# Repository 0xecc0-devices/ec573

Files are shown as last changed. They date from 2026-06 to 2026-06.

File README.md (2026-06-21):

# ec573 - Amiga 500 8MB Z2 DRAM + 2 channel IDE controller

## description
The ecc0 573 - or ec573 - is an Amiga 500 internal 8MB DRAM Zorro II expansion with 2 channel autoboot IDE controller sitting under the MC68000 CPU. It does fit into a standard Amiga 500 Mainboard interfering with neither ROM nor expansion connector.

### rendered pcb
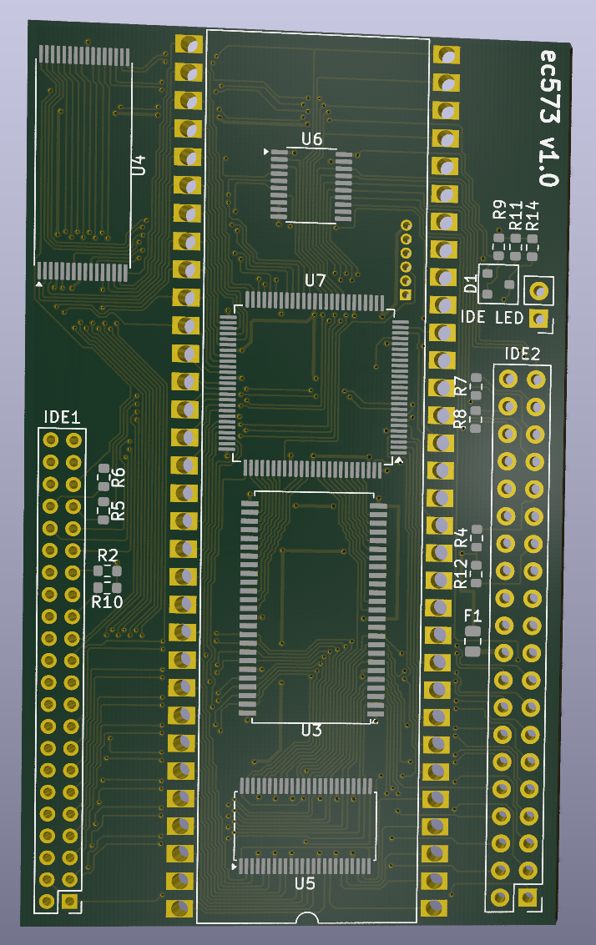
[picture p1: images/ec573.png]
rendered ec573 v1.0 pcb


### real pcb
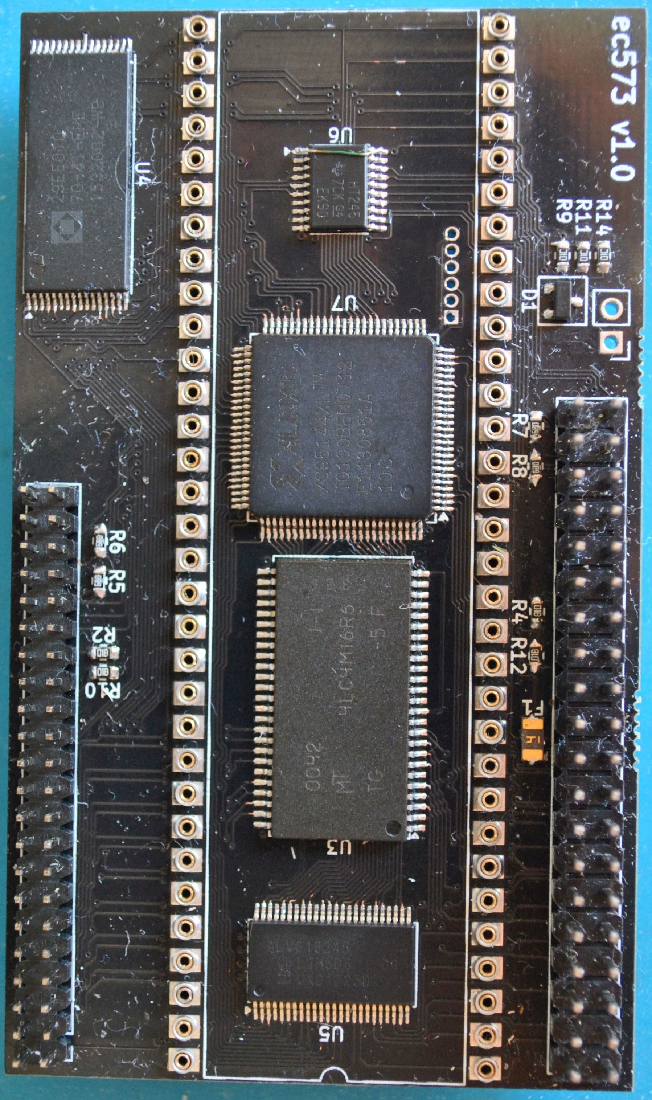
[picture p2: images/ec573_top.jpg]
real hardware ec573 v1.0

### fitted into A500
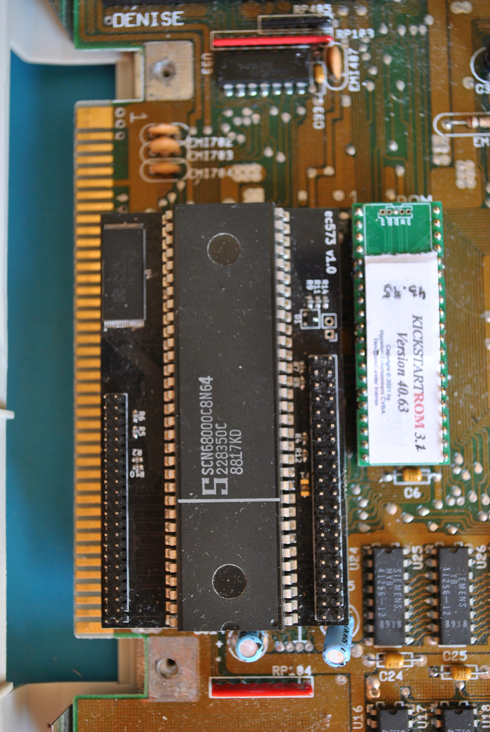
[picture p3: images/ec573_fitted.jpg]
ec573 v1.0 fitted into A500


DRAM and IDE controller are added using Amiga autoconfig mechanism with chain snooping. The expansion requires at least Kickstart 2.04 (v37.299).

## features

 - 8MB DRAM Zorro II memory expansion
  - IDE controller with 2 channels for 4 devices using the fabulous [lide.device](https://github.com/LIV2/lide.device)
 - full Zorro II autoconfig
 - jumperless
 - 2,5" IDE connector
 - 3,5" IDE connector with +5V power supply (fused on pin 20)
 - IDE LED connector
 - 128kB IDE controller ROM with CD boot capability
 - IDE autoboot ROM in circuit flash updateable
 - compatible with Kickstart v37.299 (2.04) and later

## technical details
 - 8MB DRAM mapped into Amiga's Zorro II memory address space ($20.0000 - $9F.FFFF)
 - 128kB IDE controller mapped as I/O device into Amiga's Zorro II I/O address space
 - 15,6 &#xb5;S DRAM CBR refresh

## limitations
The ecc0 573 has been designed to achieve several goals. This leaves the finished design with limitations which are intended, yet to be made transparent.

1. Due to the absense of Amiga Zorro Autoconfig signals **cfgin** and **cfgout** on the CPU slot, a snooping mechanism waits for all other devices to be configured first. This snooping mechanism needs at least Kickstart v37.299 to work.
2. Neither DRAM nor IDE controller are deactivateable.
3. The Zorro II DRAM size is fixed to 8MB. If another autoconfig device is claiming any memory before, none of the expansion's DRAM will be available.
4. The IDE controller uses [lide.device](https://github.com/LIV2/lide.device) by Matt Harlum as autoboot firmware thus inheriting all it's limitations.
5. The expansion always configures last in the autoconfiguration chain and uses the remaining resources available.
<!--stackedit_data:
eyJoaXN0b3J5IjpbMTAzMzAxODg2NSwtMTc1ODM2NjkzMCwxMD
k5NTEyNDgxXX0=
-->

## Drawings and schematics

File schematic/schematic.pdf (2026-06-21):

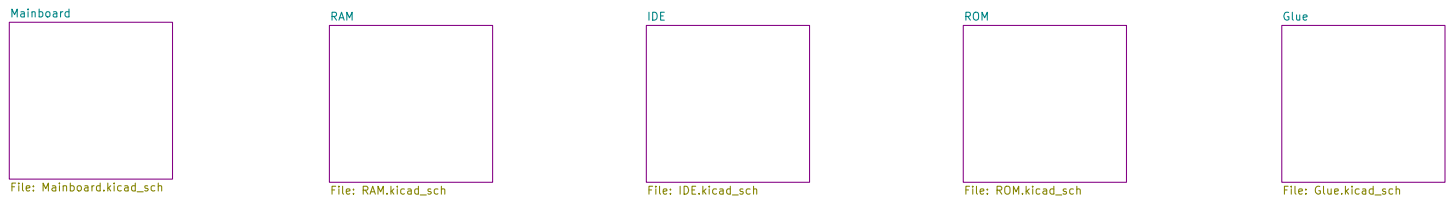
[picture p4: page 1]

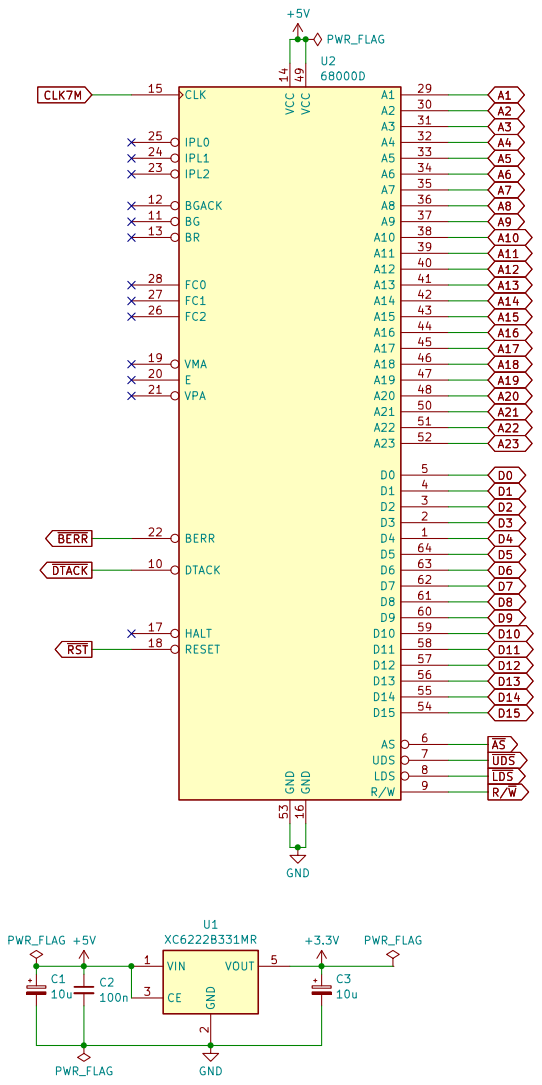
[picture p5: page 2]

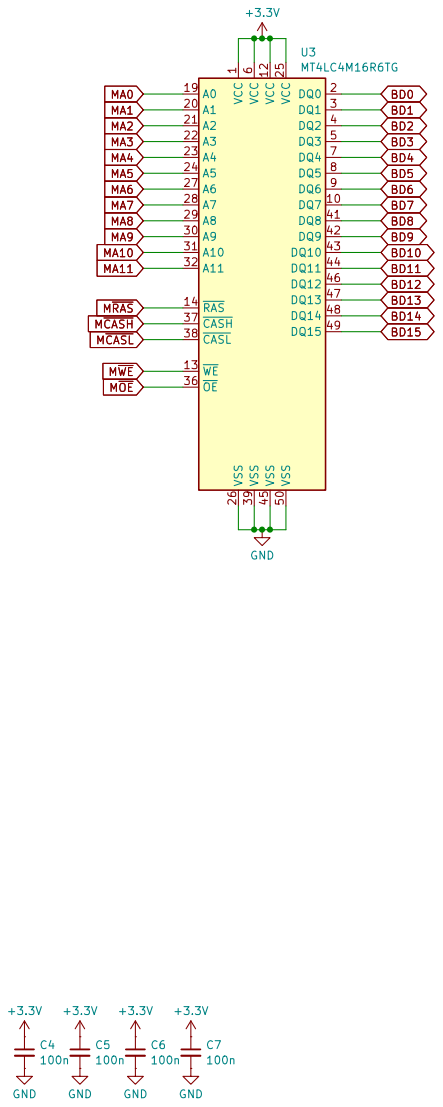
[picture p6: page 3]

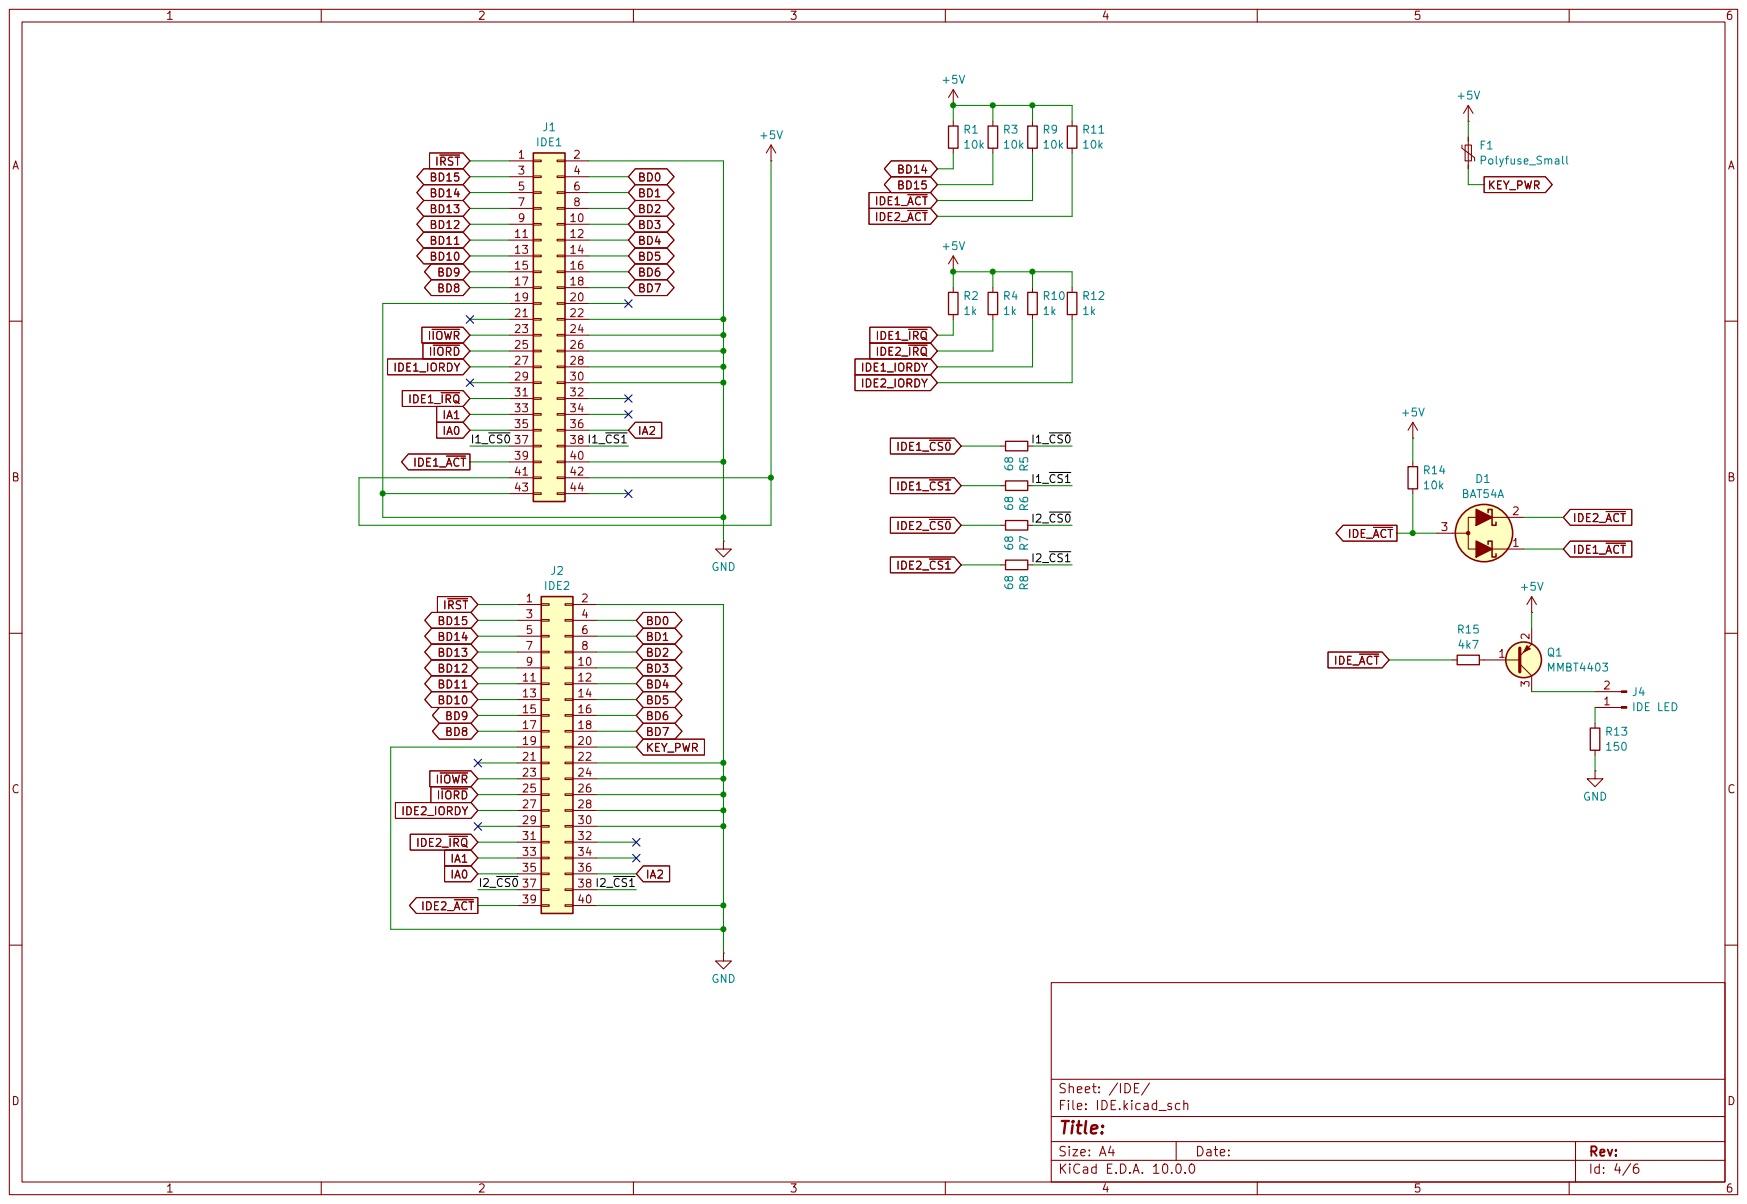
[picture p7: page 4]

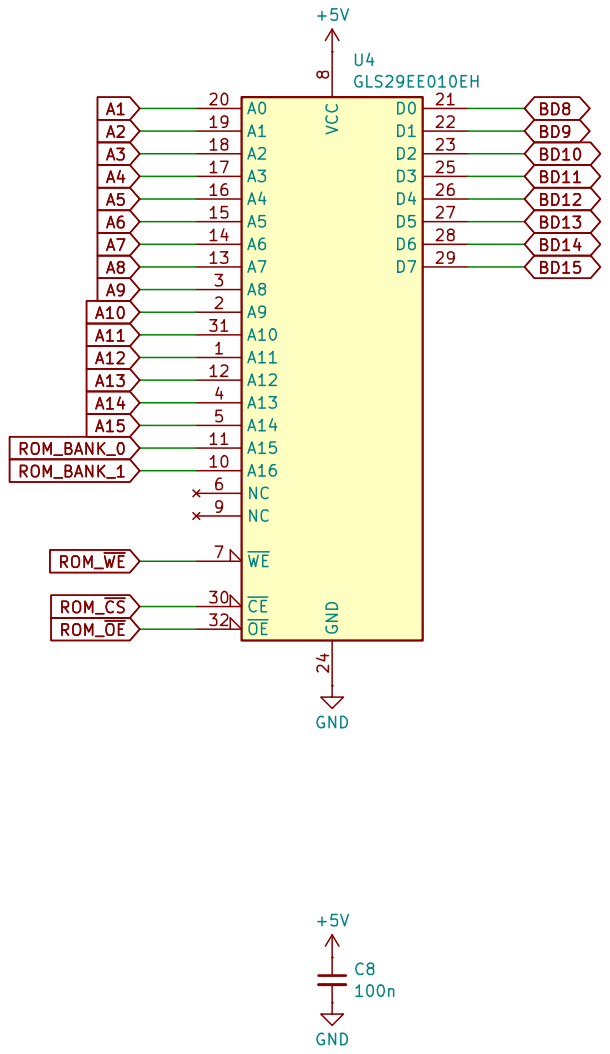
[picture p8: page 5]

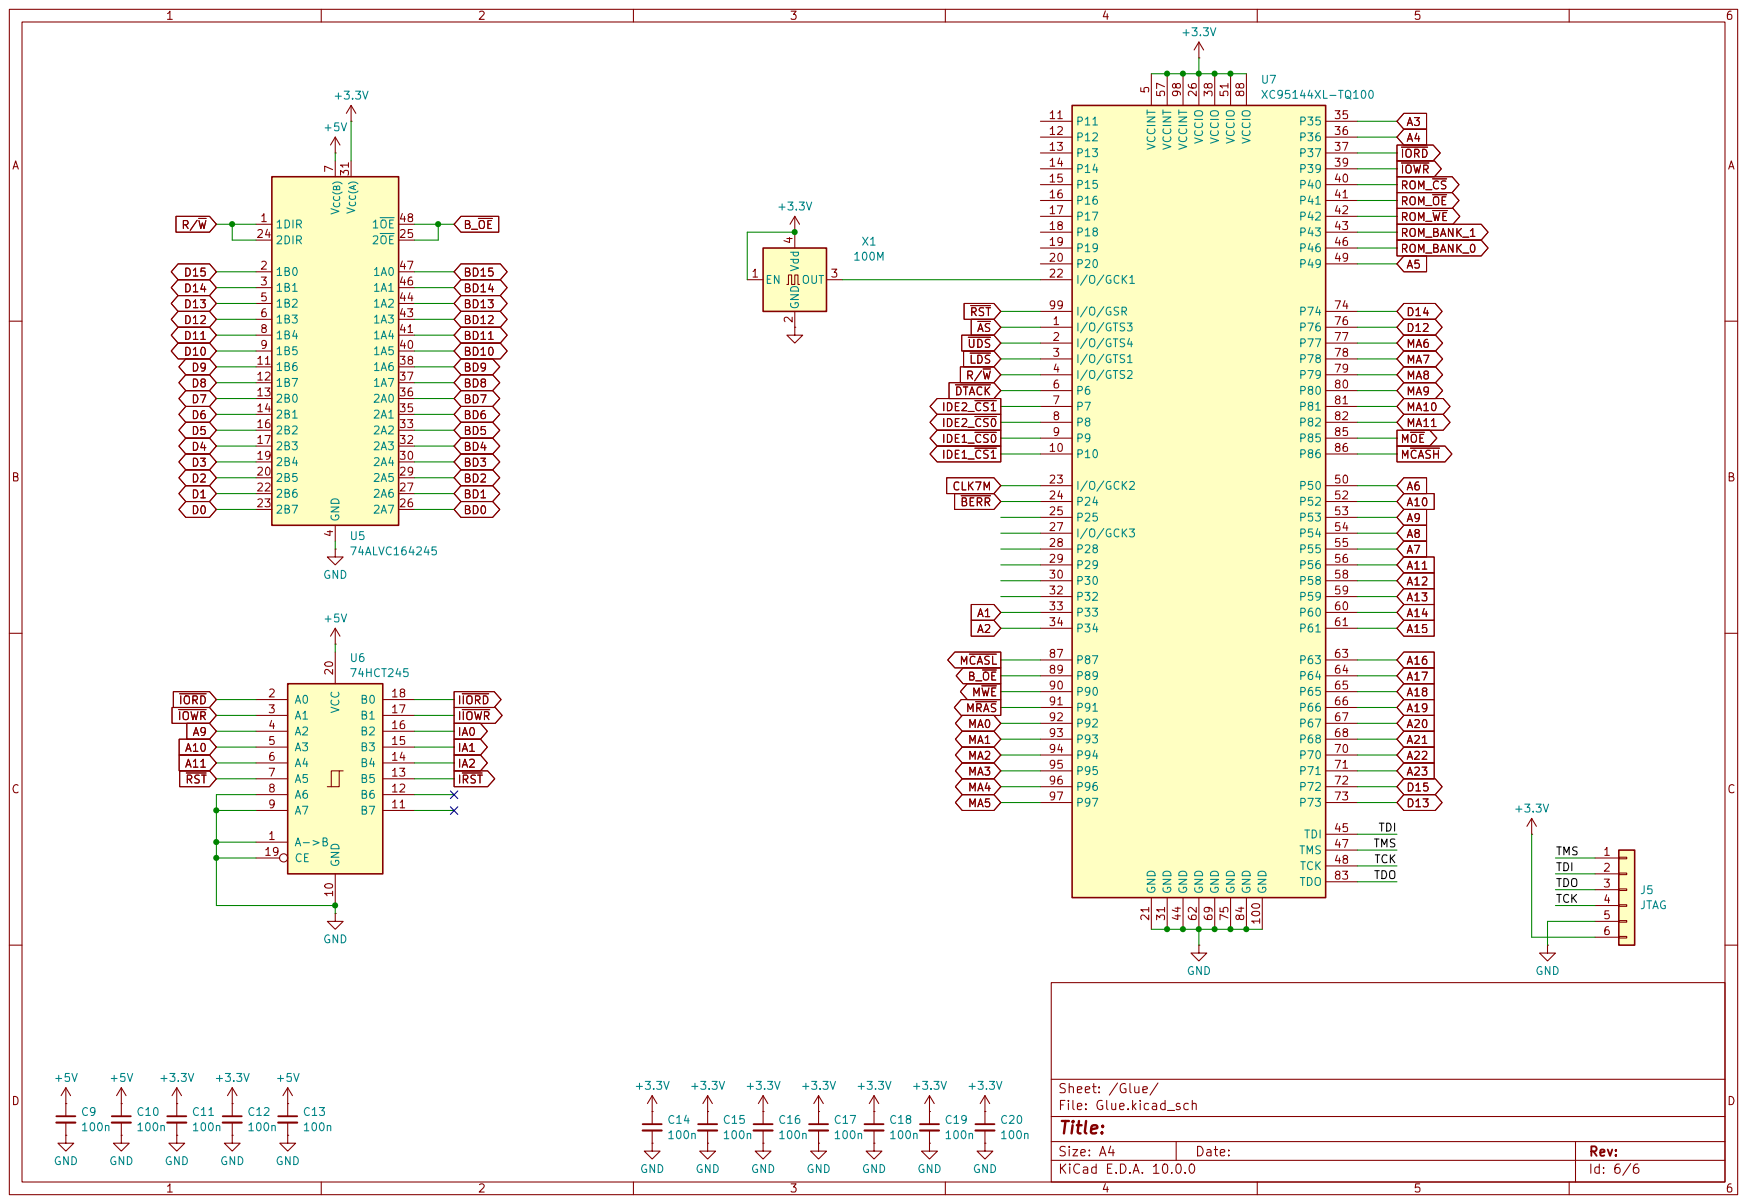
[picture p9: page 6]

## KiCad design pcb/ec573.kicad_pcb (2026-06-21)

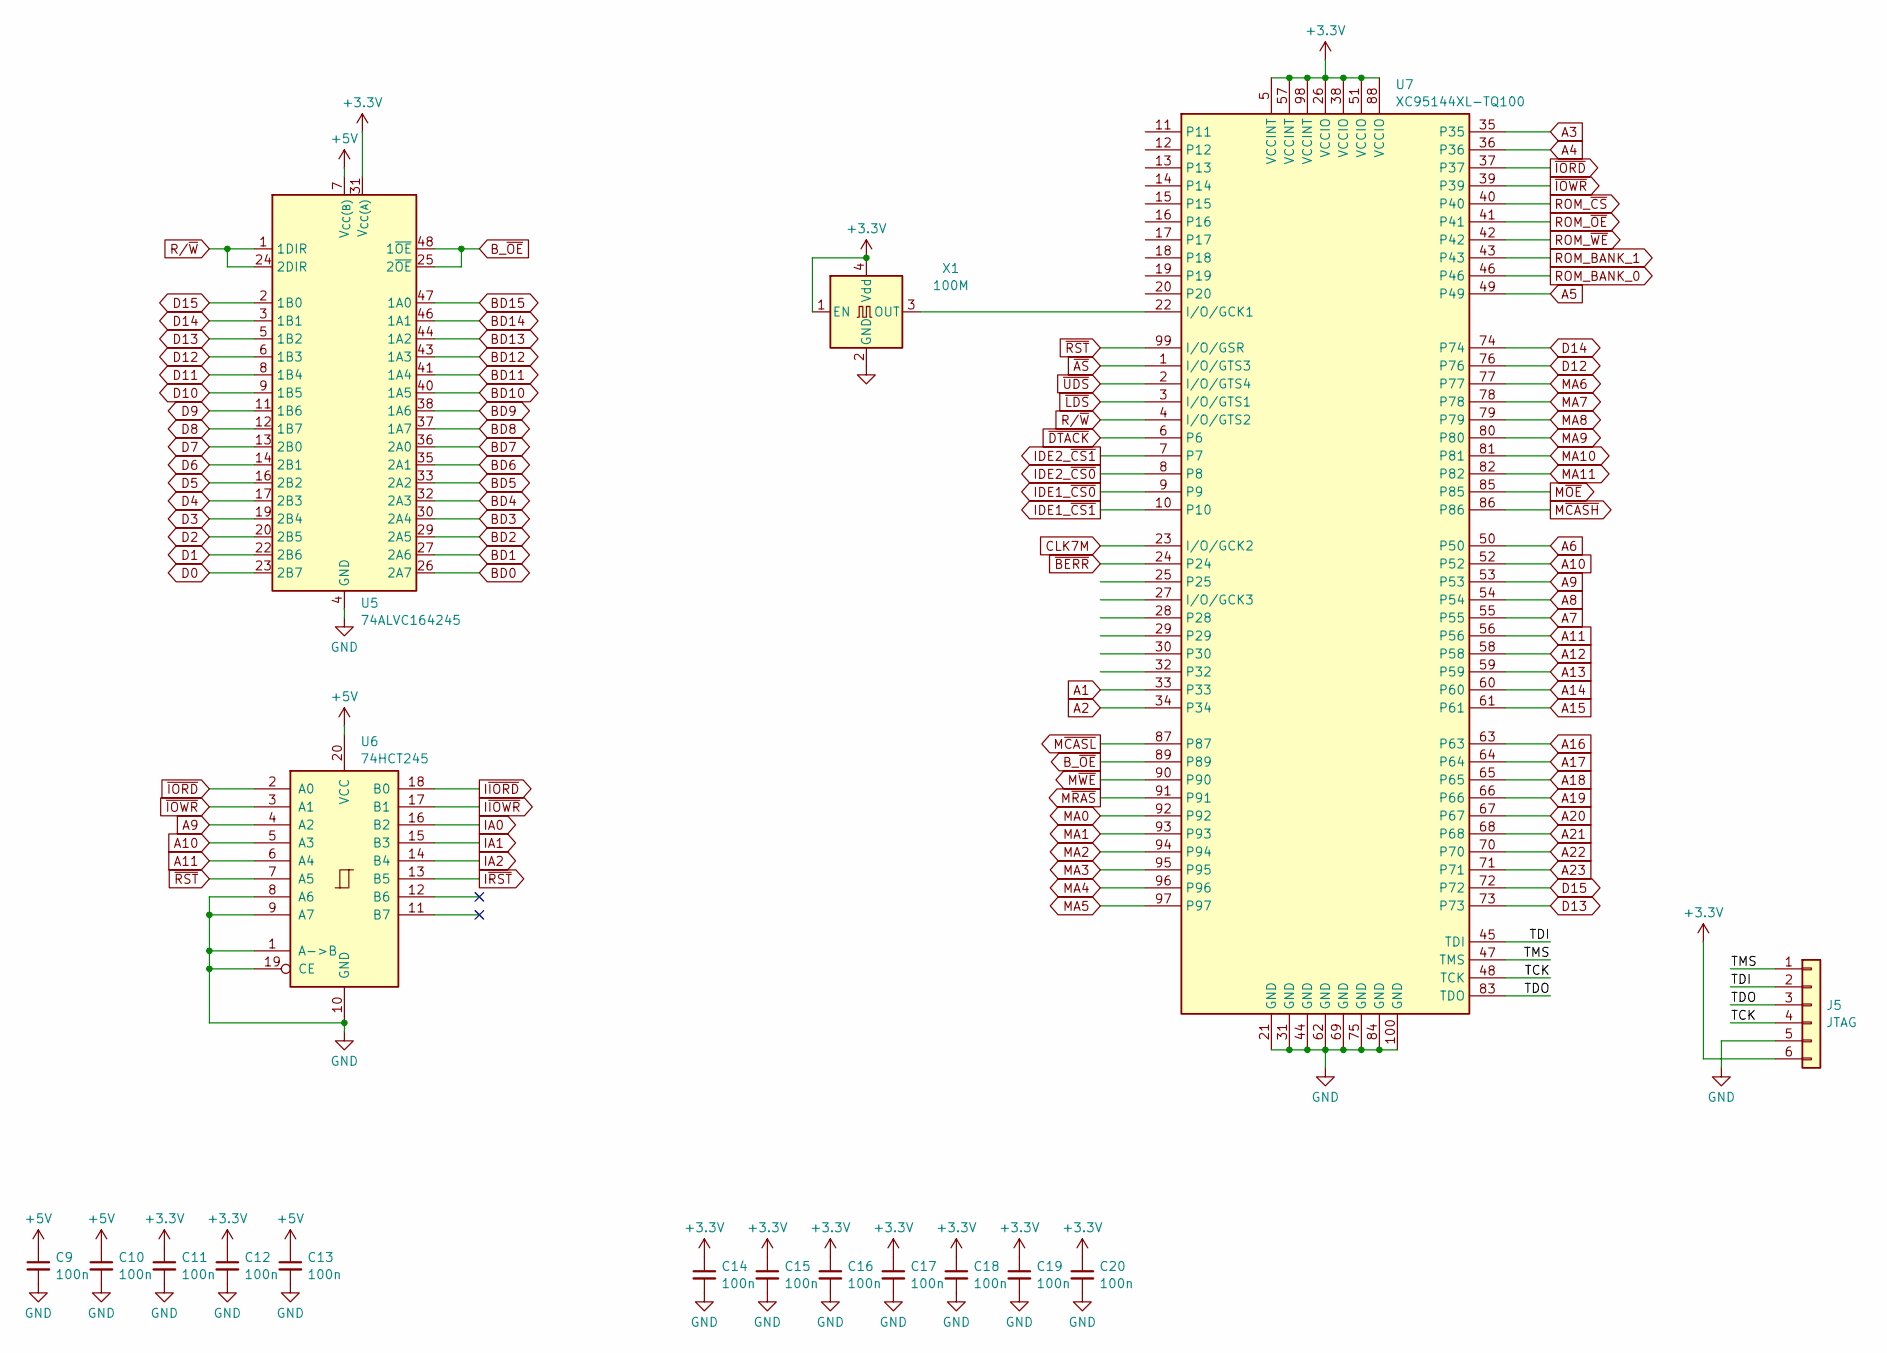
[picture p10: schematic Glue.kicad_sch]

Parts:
C9, C10, C11, C12, C13, C14, C15, C16, C17, C18, C19, C20: 100n; C_0603_1608Metric
J5: JTAG; PinHeader_1x06_P1.27mm_Vertical
U5: 74ALVC164245; TSSOP-48_6.1x12.5mm_P0.5mm
U6: 74HCT245; TSSOP-20_4.4x6.5mm_P0.65mm
U7: XC95144XL-TQ100; TQFP-100_14x14mm_P0.5mm
X1: 100M; Oscillator_SMD_Abracon_ASE-4Pin_3.2x2.5mm

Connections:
+3.3V: C11.1, C12.1, C14.1, C15.1, C16.1, C17.1, C18.1, C19.1, C20.1, J5.6, U5.31 (V_{CC(A)}), U5.42 (V_{CC(A)}), U7.5 (VCCINT), U7.26 (VCCIO), U7.38 (VCCIO), U7.51 (VCCIO), U7.57 (VCCINT), U7.88 (VCCIO), U7.98 (VCCINT), X1.1 (EN), X1.4 (Vdd); also elsewhere on the board
+5V: C9.1, C10.1, C13.1, U5.7 (V_{CC(B)}), U5.18 (V_{CC(B)}), U6.20 (VCC); also elsewhere on the board
/Glue/TCK: J5.4, U7.48 (TCK)
/Glue/TDI: J5.2, U7.45 (TDI)
/Glue/TDO: J5.3, U7.83 (TDO)
/Glue/TMS: J5.1, U7.47 (TMS)
A1: U7.33; also elsewhere on the board
A2: U7.34; also elsewhere on the board
A3: U7.35; also elsewhere on the board
A4: U7.36; also elsewhere on the board
A5: U7.49; also elsewhere on the board
A6: U7.50; also elsewhere on the board
A7: U7.55; also elsewhere on the board
A8: U7.54; also elsewhere on the board
A9: U6.4 (A2), U7.53; also elsewhere on the board
A10: U6.5 (A3), U7.52; also elsewhere on the board
A11: U6.6 (A4), U7.56; also elsewhere on the board
A12: U7.58; also elsewhere on the board
A13: U7.59; also elsewhere on the board
A14: U7.60; also elsewhere on the board
A15: U7.61; also elsewhere on the board
A16: U7.63; also elsewhere on the board
A17: U7.64; also elsewhere on the board
A18: U7.65; also elsewhere on the board
A19: U7.66; also elsewhere on the board
A20: U7.67; also elsewhere on the board
A21: U7.68; also elsewhere on the board
A22: U7.70; also elsewhere on the board
A23: U7.71; also elsewhere on the board
BD0: U5.26 (2A7); also elsewhere on the board
BD1: U5.27 (2A6); also elsewhere on the board
BD2: U5.29 (2A5); also elsewhere on the board
BD3: U5.30 (2A4); also elsewhere on the board
BD4: U5.32 (2A3); also elsewhere on the board
BD5: U5.33 (2A2); also elsewhere on the board
BD6: U5.35 (2A1); also elsewhere on the board
BD7: U5.36 (2A0); also elsewhere on the board
BD8: U5.37 (1A7); also elsewhere on the board
BD9: U5.38 (1A6); also elsewhere on the board
BD10: U5.40 (1A5); also elsewhere on the board
BD11: U5.41 (1A4); also elsewhere on the board
BD12: U5.43 (1A3); also elsewhere on the board
BD13: U5.44 (1A2); also elsewhere on the board
BD14: U5.46 (1A1); also elsewhere on the board
BD15: U5.47 (1A0); also elsewhere on the board
B_~OE: U5.25 (2~OE), U5.48 (1~OE), U7.89
CLK7M: U7.23 (I/O/GCK2); also elsewhere on the board
D0: U5.23 (2B7); also elsewhere on the board
D1: U5.22 (2B6); also elsewhere on the board
D2: U5.20 (2B5); also elsewhere on the board
D3: U5.19 (2B4); also elsewhere on the board
D4: U5.17 (2B3); also elsewhere on the board
D5: U5.16 (2B2); also elsewhere on the board
D6: U5.14 (2B1); also elsewhere on the board
D7: U5.13 (2B0); also elsewhere on the board
D8: U5.12 (1B7); also elsewhere on the board
D9: U5.11 (1B6); also elsewhere on the board
D10: U5.9 (1B5); also elsewhere on the board
D11: U5.8 (1B4); also elsewhere on the board
D12: U5.6 (1B3), U7.76; also elsewhere on the board
D13: U5.5 (1B2), U7.73; also elsewhere on the board
D14: U5.3 (1B1), U7.74; also elsewhere on the board
D15: U5.2 (1B0), U7.72; also elsewhere on the board
GND: C9.2, C10.2, C11.2, C12.2, C13.2, C14.2, C15.2, C16.2, C17.2, C18.2, C19.2, C20.2, J5.5, U5.4 (GND), U5.10 (GND), U5.15 (GND), U5.21 (GND), U5.28 (GND), U5.34 (GND), U5.39 (GND), U5.45 (GND), U6.1 (A->B), U6.8 (A6), U6.9 (A7), U6.10 (GND), U6.19 (CE), U7.21 (GND), U7.31 (GND), U7.44 (GND), U7.62 (GND), U7.69 (GND), U7.75 (GND), U7.84 (GND), U7.100 (GND), X1.2 (GND); also elsewhere on the board
IA0: U6.16 (B2); also elsewhere on the board
IA1: U6.15 (B3); also elsewhere on the board
IA2: U6.14 (B4); also elsewhere on the board
IDE1_~CS0: U7.9; also elsewhere on the board
IDE1_~CS1: U7.10; also elsewhere on the board
IDE2_~CS0: U7.8; also elsewhere on the board
IDE2_~CS1: U7.7; also elsewhere on the board
I~IORD: U6.18 (B0); also elsewhere on the board
I~IOWR: U6.17 (B1); also elsewhere on the board
I~RST: U6.13 (B5); also elsewhere on the board
MA0: U7.92; also elsewhere on the board
MA1: U7.93; also elsewhere on the board
MA2: U7.94; also elsewhere on the board
MA3: U7.95; also elsewhere on the board
MA4: U7.96; also elsewhere on the board
MA5: U7.97; also elsewhere on the board
MA6: U7.77; also elsewhere on the board
MA7: U7.78; also elsewhere on the board
MA8: U7.79; also elsewhere on the board
MA9: U7.80; also elsewhere on the board
MA10: U7.81; also elsewhere on the board
MA11: U7.82; also elsewhere on the board
M~CASH: U7.86; also elsewhere on the board
M~CASL: U7.87; also elsewhere on the board
M~OE: U7.85; also elsewhere on the board
M~RAS: U7.91; also elsewhere on the board
M~WE: U7.90; also elsewhere on the board
unnamed: U7.22 (I/O/GCK1), X1.3 (OUT)
ROM_BANK_0: U7.46; also elsewhere on the board
ROM_BANK_1: U7.43; also elsewhere on the board
ROM_~CS: U7.40; also elsewhere on the board
ROM_~OE: U7.41; also elsewhere on the board
ROM_~WE: U7.42; also elsewhere on the board
R/~W: U5.1 (1DIR), U5.24 (2DIR), U7.4 (I/O/GTS2); also elsewhere on the board
~AS: U7.1 (I/O/GTS3); also elsewhere on the board
~BERR: U7.24; also elsewhere on the board
~DTACK: U7.6; also elsewhere on the board
~IORD: U6.2 (A0), U7.37
~IOWR: U6.3 (A1), U7.39
~LDS: U7.3 (I/O/GTS1); also elsewhere on the board
~RST: U6.7 (A5), U7.99 (I/O/GSR); also elsewhere on the board
~UDS: U7.2 (I/O/GTS4); also elsewhere on the board

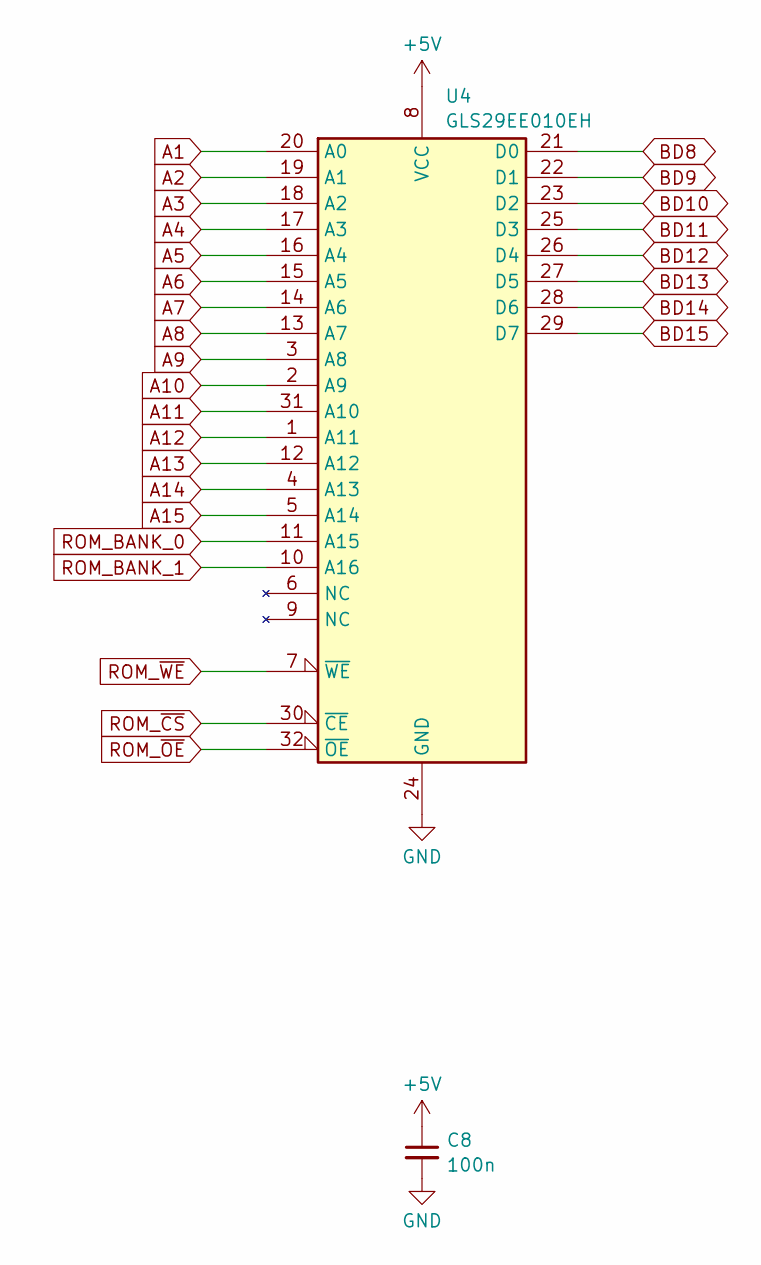
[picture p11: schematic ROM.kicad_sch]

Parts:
C8: 100n; C_0603_1608Metric
U4: GLS29EE010EH; TSOP-I-32_18.4x8mm_P0.5mm

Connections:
+5V: C8.1, U4.8 (VCC); also elsewhere on the board
A1: U4.20 (A0); also elsewhere on the board
A2: U4.19 (A1); also elsewhere on the board
A3: U4.18 (A2); also elsewhere on the board
A4: U4.17 (A3); also elsewhere on the board
A5: U4.16 (A4); also elsewhere on the board
A6: U4.15 (A5); also elsewhere on the board
A7: U4.14 (A6); also elsewhere on the board
A8: U4.13 (A7); also elsewhere on the board
A9: U4.3 (A8); also elsewhere on the board
A10: U4.2 (A9); also elsewhere on the board
A11: U4.31 (A10); also elsewhere on the board
A12: U4.1 (A11); also elsewhere on the board
A13: U4.12 (A12); also elsewhere on the board
A14: U4.4 (A13); also elsewhere on the board
A15: U4.5 (A14); also elsewhere on the board
BD8: U4.21 (D0); also elsewhere on the board
BD9: U4.22 (D1); also elsewhere on the board
BD10: U4.23 (D2); also elsewhere on the board
BD11: U4.25 (D3); also elsewhere on the board
BD12: U4.26 (D4); also elsewhere on the board
BD13: U4.27 (D5); also elsewhere on the board
BD14: U4.28 (D6); also elsewhere on the board
BD15: U4.29 (D7); also elsewhere on the board
GND: C8.2, U4.24 (GND); also elsewhere on the board
ROM_BANK_0: U4.11 (A15); also elsewhere on the board
ROM_BANK_1: U4.10 (A16); also elsewhere on the board
ROM_~CS: U4.30 (~CE); also elsewhere on the board
ROM_~OE: U4.32 (~OE); also elsewhere on the board
ROM_~WE: U4.7 (~WE); also elsewhere on the board

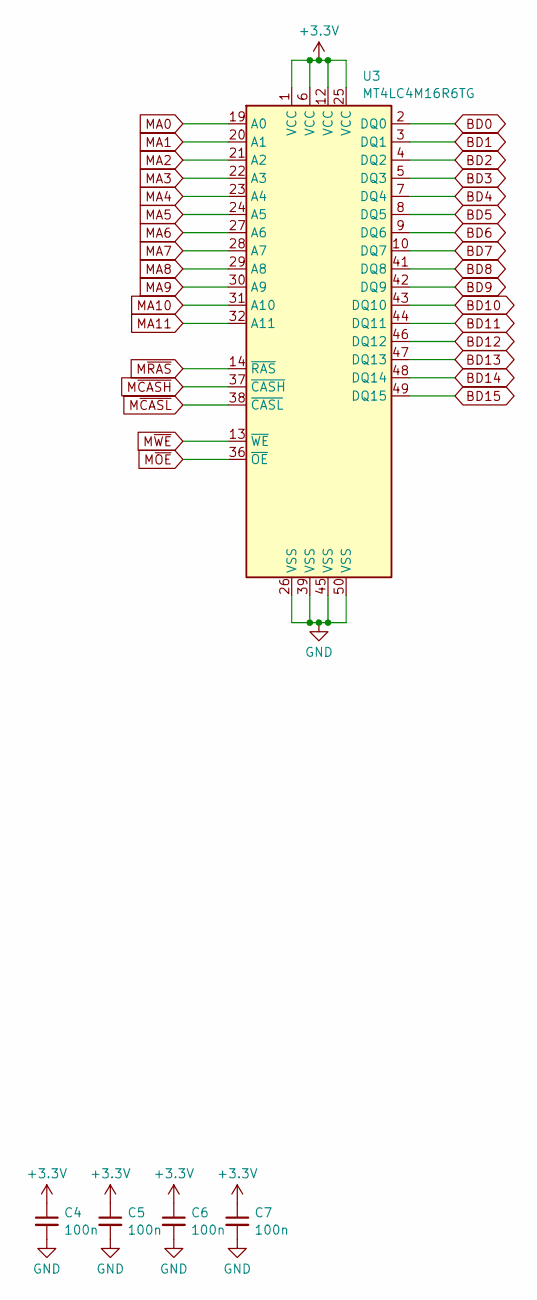
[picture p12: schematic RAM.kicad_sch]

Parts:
C4, C5, C6, C7: 100n; C_0603_1608Metric
U3: MT4LC4M16R6TG; TSOP-II-50_20.86x10.16mm_P0.8mm

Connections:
+3.3V: C4.1, C5.1, C6.1, C7.1, U3.1 (VCC), U3.6 (VCC), U3.12 (VCC), U3.25 (VCC); also elsewhere on the board
BD0: U3.2 (DQ0); also elsewhere on the board
BD1: U3.3 (DQ1); also elsewhere on the board
BD2: U3.4 (DQ2); also elsewhere on the board
BD3: U3.5 (DQ3); also elsewhere on the board
BD4: U3.7 (DQ4); also elsewhere on the board
BD5: U3.8 (DQ5); also elsewhere on the board
BD6: U3.9 (DQ6); also elsewhere on the board
BD7: U3.10 (DQ7); also elsewhere on the board
BD8: U3.41 (DQ8); also elsewhere on the board
BD9: U3.42 (DQ9); also elsewhere on the board
BD10: U3.43 (DQ10); also elsewhere on the board
BD11: U3.44 (DQ11); also elsewhere on the board
BD12: U3.46 (DQ12); also elsewhere on the board
BD13: U3.47 (DQ13); also elsewhere on the board
BD14: U3.48 (DQ14); also elsewhere on the board
BD15: U3.49 (DQ15); also elsewhere on the board
GND: C4.2, C5.2, C6.2, C7.2, U3.26 (VSS), U3.39 (VSS), U3.45 (VSS), U3.50 (VSS); also elsewhere on the board
MA0: U3.19 (A0); also elsewhere on the board
MA1: U3.20 (A1); also elsewhere on the board
MA2: U3.21 (A2); also elsewhere on the board
MA3: U3.22 (A3); also elsewhere on the board
MA4: U3.23 (A4); also elsewhere on the board
MA5: U3.24 (A5); also elsewhere on the board
MA6: U3.27 (A6); also elsewhere on the board
MA7: U3.28 (A7); also elsewhere on the board
MA8: U3.29 (A8); also elsewhere on the board
MA9: U3.30 (A9); also elsewhere on the board
MA10: U3.31 (A10); also elsewhere on the board
MA11: U3.32 (A11); also elsewhere on the board
M~CASH: U3.37 (~CASH); also elsewhere on the board
M~CASL: U3.38 (~CASL); also elsewhere on the board
M~OE: U3.36 (~OE); also elsewhere on the board
M~RAS: U3.14 (~RAS); also elsewhere on the board
M~WE: U3.13 (~WE); also elsewhere on the board

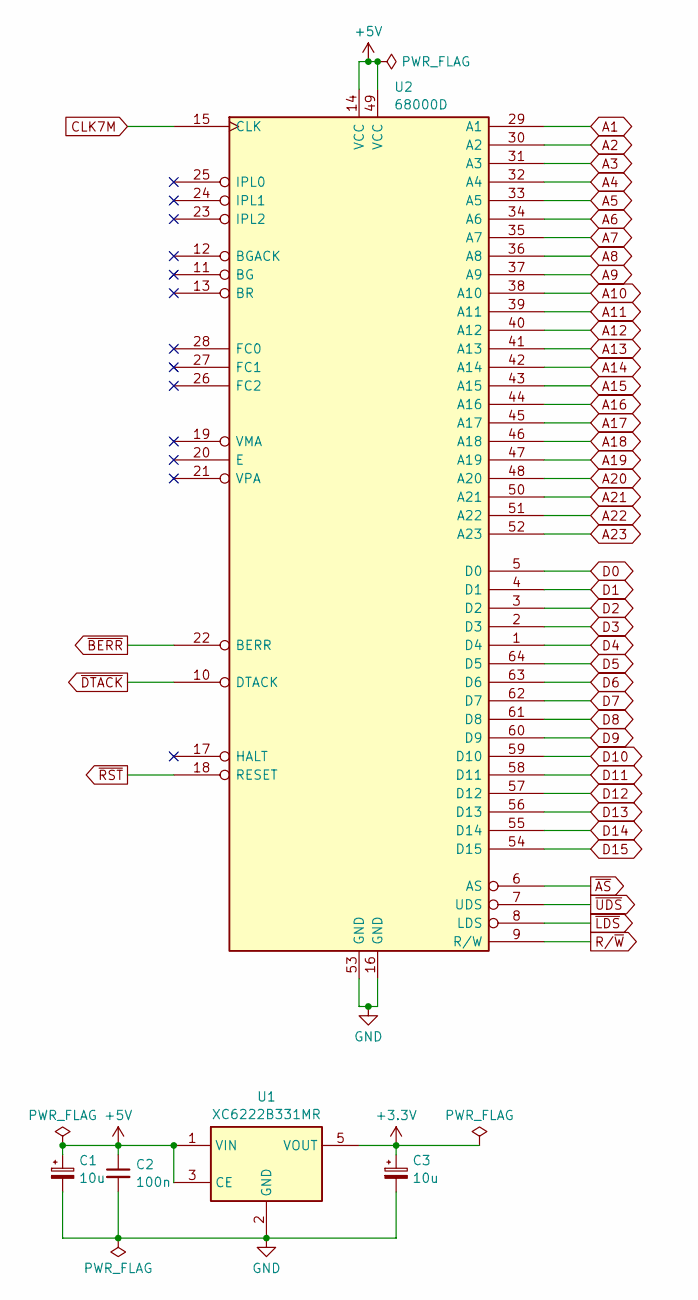
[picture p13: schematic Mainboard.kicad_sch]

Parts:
C1, C3: 10u; CP_EIA-3216-10_Kemet-I
C2: 100n; C_0603_1608Metric
U1: XC6222B331MR; SOT-23-5
U2: 68000D; DIP-64_W22.86mm_LongPads

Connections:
+3.3V: C3.1, U1.5 (VOUT); also elsewhere on the board
+5V: C1.1, C2.1, U1.1 (VIN), U1.3 (CE), U2.14 (VCC), U2.49 (VCC); also elsewhere on the board
A1: U2.29 (A1); also elsewhere on the board
A2: U2.30 (A2); also elsewhere on the board
A3: U2.31 (A3); also elsewhere on the board
A4: U2.32 (A4); also elsewhere on the board
A5: U2.33 (A5); also elsewhere on the board
A6: U2.34 (A6); also elsewhere on the board
A7: U2.35 (A7); also elsewhere on the board
A8: U2.36 (A8); also elsewhere on the board
A9: U2.37 (A9); also elsewhere on the board
A10: U2.38 (A10); also elsewhere on the board
A11: U2.39 (A11); also elsewhere on the board
A12: U2.40 (A12); also elsewhere on the board
A13: U2.41 (A13); also elsewhere on the board
A14: U2.42 (A14); also elsewhere on the board
A15: U2.43 (A15); also elsewhere on the board
A16: U2.44 (A16); also elsewhere on the board
A17: U2.45 (A17); also elsewhere on the board
A18: U2.46 (A18); also elsewhere on the board
A19: U2.47 (A19); also elsewhere on the board
A20: U2.48 (A20); also elsewhere on the board
A21: U2.50 (A21); also elsewhere on the board
A22: U2.51 (A22); also elsewhere on the board
A23: U2.52 (A23); also elsewhere on the board
CLK7M: U2.15 (CLK); also elsewhere on the board
D0: U2.5 (D0); also elsewhere on the board
D1: U2.4 (D1); also elsewhere on the board
D2: U2.3 (D2); also elsewhere on the board
D3: U2.2 (D3); also elsewhere on the board
D4: U2.1 (D4); also elsewhere on the board
D5: U2.64 (D5); also elsewhere on the board
D6: U2.63 (D6); also elsewhere on the board
D7: U2.62 (D7); also elsewhere on the board
D8: U2.61 (D8); also elsewhere on the board
D9: U2.60 (D9); also elsewhere on the board
D10: U2.59 (D10); also elsewhere on the board
D11: U2.58 (D11); also elsewhere on the board
D12: U2.57 (D12); also elsewhere on the board
D13: U2.56 (D13); also elsewhere on the board
D14: U2.55 (D14); also elsewhere on the board
D15: U2.54 (D15); also elsewhere on the board
GND: C1.2, C2.2, C3.2, U1.2 (GND), U2.16 (GND), U2.53 (GND); also elsewhere on the board
R/~W: U2.9 (R/W); also elsewhere on the board
~AS: U2.6 (AS); also elsewhere on the board
~BERR: U2.22 (BERR); also elsewhere on the board
~DTACK: U2.10 (DTACK); also elsewhere on the board
~LDS: U2.8 (LDS); also elsewhere on the board
~RST: U2.18 (RESET); also elsewhere on the board
~UDS: U2.7 (UDS); also elsewhere on the board

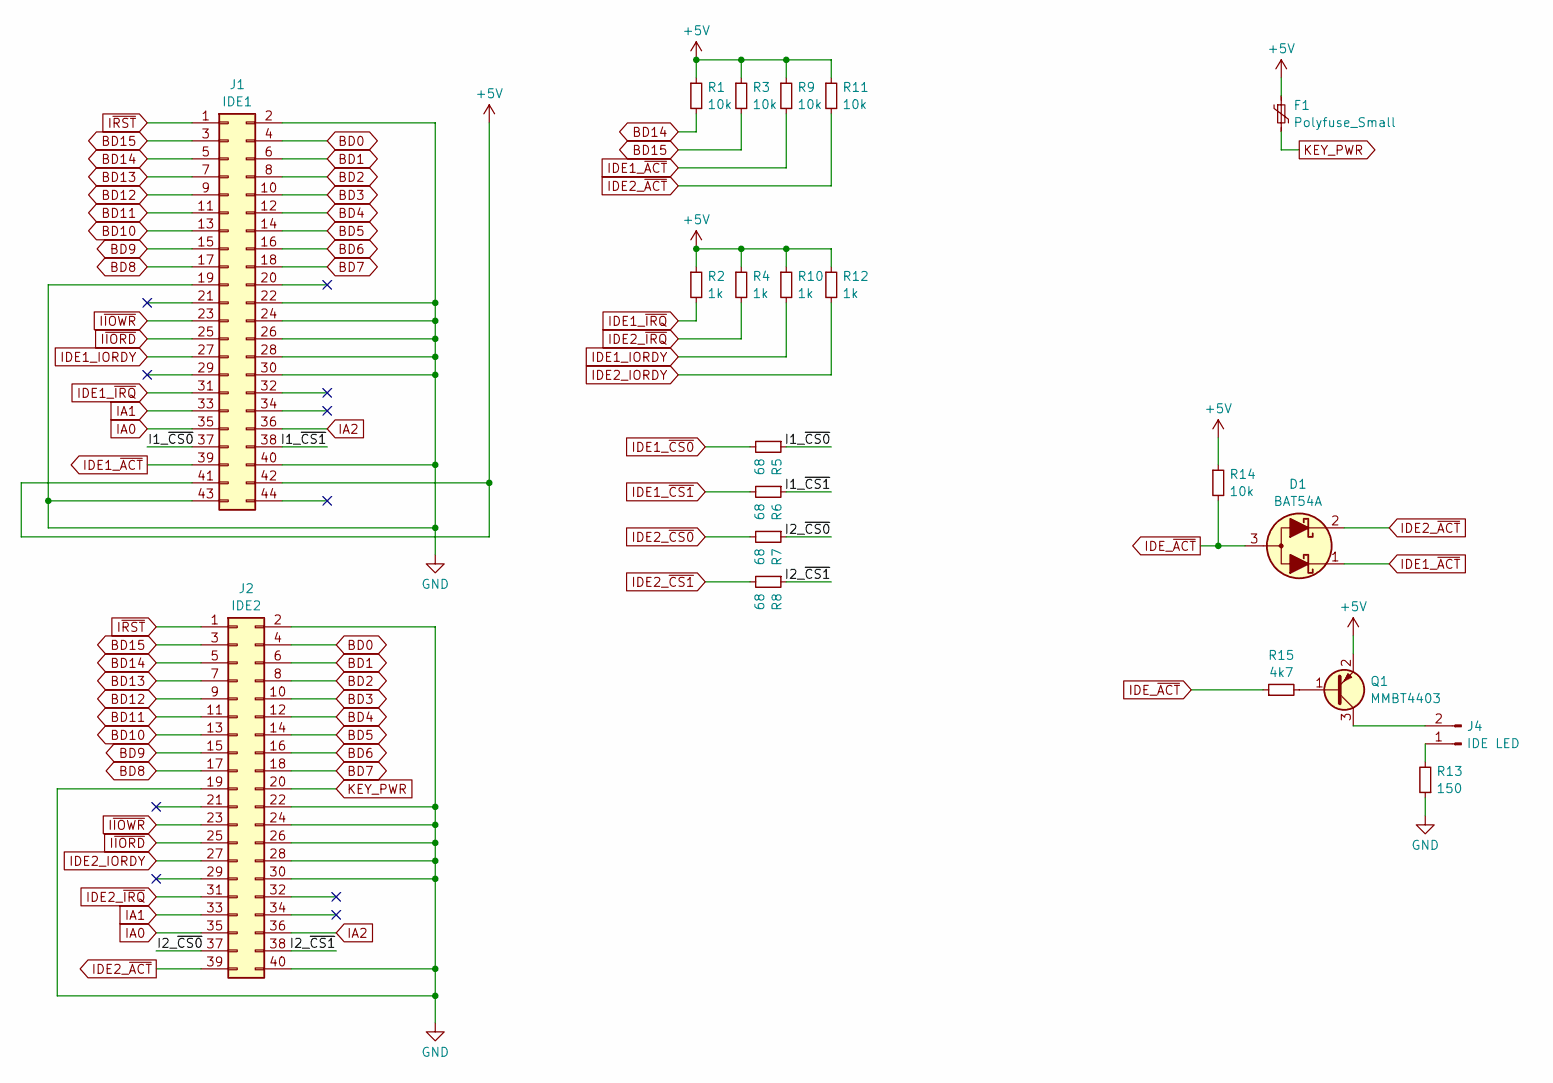
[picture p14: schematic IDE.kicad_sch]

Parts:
D1: BAT54A; SOT-23
F1: Polyfuse_Small; Fuse_0805_2012Metric
J1: IDE1; PinHeader_2x22_P2.00mm_Vertical
J2: IDE2; PinHeader_2x20_P2.54mm_Vertical
J4: IDE LED; PinHeader_1x02_P2.54mm_Vertical
Q1: MMBT4403; SOT-23
R1, R3, R9, R11, R14: 10k; R_0603_1608Metric
R2, R4, R10, R12: 1k; R_0603_1608Metric
R5, R6, R7, R8: 68; R_0603_1608Metric
R13: 150; R_0603_1608Metric
R15: 4k7; R_0603_1608Metric

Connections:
+5V: F1.1, J1.41, J1.42, Q1.2 (E), R1.1, R2.1, R3.1, R4.1, R9.1, R10.1, R11.1, R12.1, R14.1; also elsewhere on the board
/IDE/I1_~CS0: J1.37, R5.1
/IDE/I1_~CS1: J1.38, R6.1
/IDE/I2_~CS0: J2.37, R7.1
/IDE/I2_~CS1: J2.38, R8.1
BD0: J1.4, J2.4; also elsewhere on the board
BD1: J1.6, J2.6; also elsewhere on the board
BD2: J1.8, J2.8; also elsewhere on the board
BD3: J1.10, J2.10; also elsewhere on the board
BD4: J1.12, J2.12; also elsewhere on the board
BD5: J1.14, J2.14; also elsewhere on the board
BD6: J1.16, J2.16; also elsewhere on the board
BD7: J1.18, J2.18; also elsewhere on the board
BD8: J1.17, J2.17; also elsewhere on the board
BD9: J1.15, J2.15; also elsewhere on the board
BD10: J1.13, J2.13; also elsewhere on the board
BD11: J1.11, J2.11; also elsewhere on the board
BD12: J1.9, J2.9; also elsewhere on the board
BD13: J1.7, J2.7; also elsewhere on the board
BD14: J1.5, J2.5, R1.2; also elsewhere on the board
BD15: J1.3, J2.3, R3.2; also elsewhere on the board
GND: J1.2, J1.19, J1.22, J1.24, J1.26, J1.28, J1.30, J1.40, J1.43, J2.2, J2.19, J2.22, J2.24, J2.26, J2.28, J2.30, J2.40, R13.1; also elsewhere on the board
IA0: J1.35, J2.35; also elsewhere on the board
IA1: J1.33, J2.33; also elsewhere on the board
IA2: J1.36, J2.36; also elsewhere on the board
IDE1_IORDY: J1.27, R10.2
IDE1_~ACT: D1.1 (K1), J1.39, R9.2
IDE1_~CS0: R5.2; also elsewhere on the board
IDE1_~CS1: R6.2; also elsewhere on the board
IDE1_~IRQ: J1.31, R2.2
IDE2_IORDY: J2.27, R12.2
IDE2_~ACT: D1.2 (K2), J2.39, R11.2
IDE2_~CS0: R7.2; also elsewhere on the board
IDE2_~CS1: R8.2; also elsewhere on the board
IDE2_~IRQ: J2.31, R4.2
IDE_~ACT: D1.3 (A), R14.2, R15.1
I~IORD: J1.25, J2.25; also elsewhere on the board
I~IOWR: J1.23, J2.23; also elsewhere on the board
I~RST: J1.1, J2.1; also elsewhere on the board
KEY_PWR: F1.2, J2.20
unnamed: J4.1, R13.2
unnamed: J4.2, Q1.3 (C)
unnamed: Q1.1 (B), R15.2

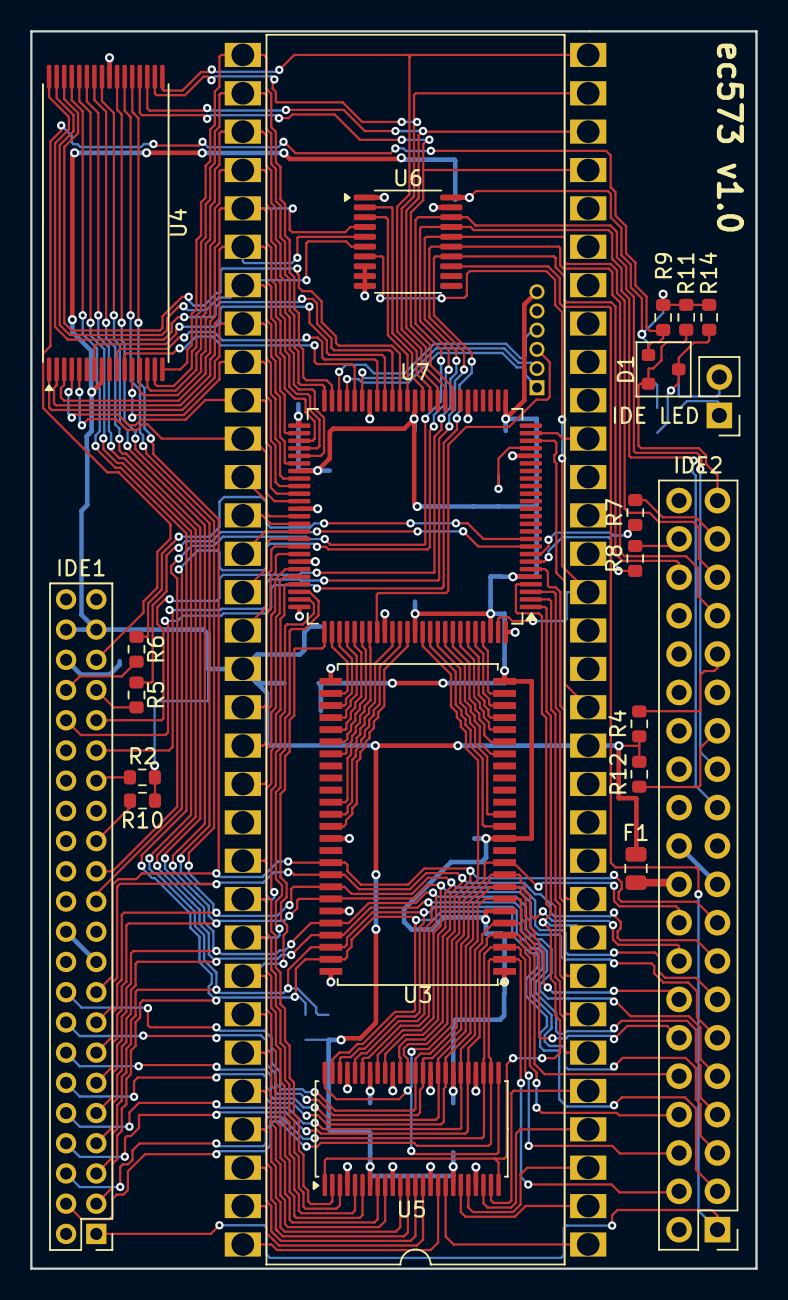
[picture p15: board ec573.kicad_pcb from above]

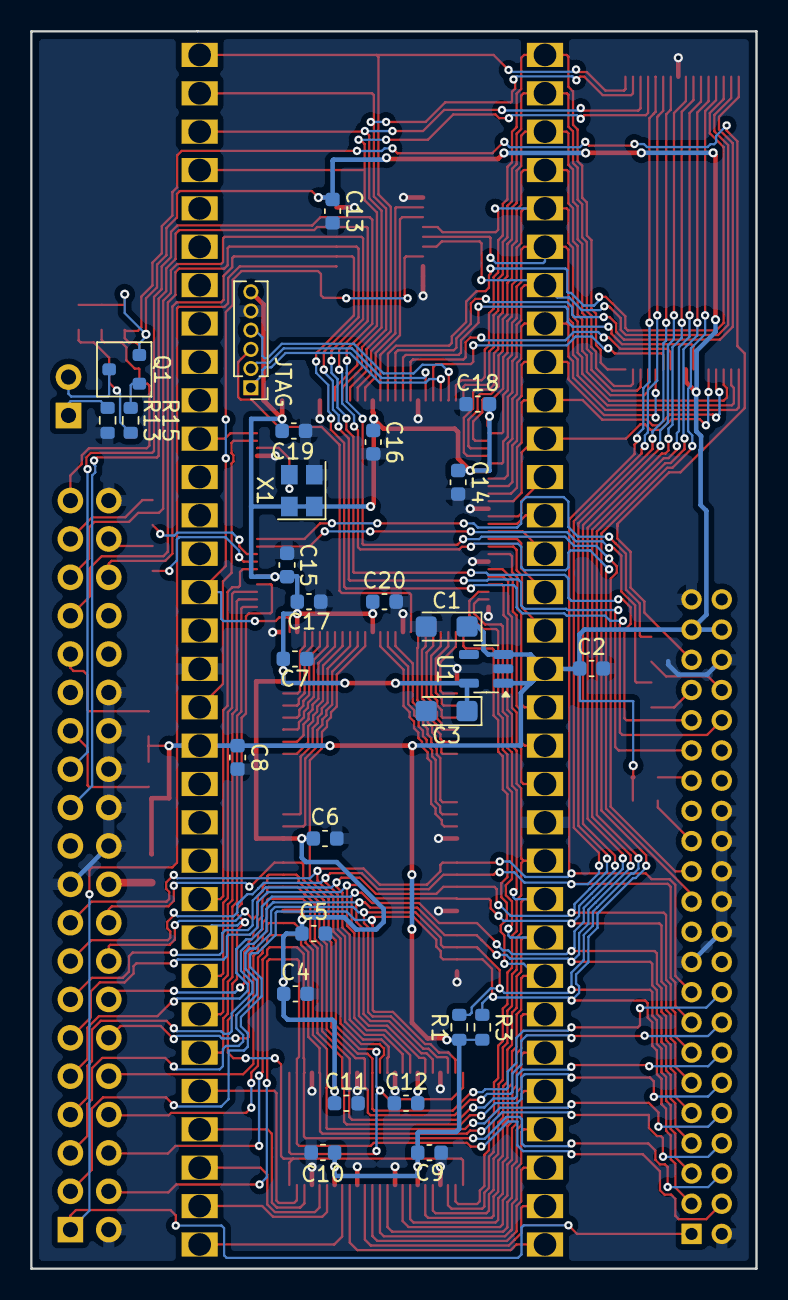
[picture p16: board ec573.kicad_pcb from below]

Board: 2 copper layers, 48.0 x 81.9 mm, 50 parts (28 on the bottom side), 121 nets.
